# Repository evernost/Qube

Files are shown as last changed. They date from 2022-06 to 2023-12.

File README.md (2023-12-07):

# Qube
LED Rubik's Cube.



Parts list
-
| Part | Ref | Order code |
|---|---|---|
| µC | STM32G431KB  | Farnell: 3132405 |
| LED driver  | PCA9955B | Farnell: 2759859 |
| 3.3V LDO | LD1117S33CTR | Farnell: 1467779 |
| Push button | KSG222GLFS | Farnell: 2845714 |

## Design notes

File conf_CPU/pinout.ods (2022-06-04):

pin | designation | function (CPU) | function (PCB) | match?
1 | PE2 | SAI1_MCLK_A | AUDIO_I2S_MCLK
2 | PE3 | SAI1_SD_B | AUDIO_I2S_SD_ADC
3 | PE4 | SAI1_FS_A | AUDIO_I2S_LRCLK_DAC
4 | PE5 | SAI1_SCK_A | AUDIO_I2S_BCLK_DAC
5 | PE6 | SPI4_MOSI | SPI MOSI LEDs
6 | VBAT |  | VDD
7 | PC13 | not used | x
8 | PC14 | not used | x
9 | PC15 | not used | x
10 | PF0 | output | debug LED 0
11 | PF1 | output | debug LED 1
12 | PF2 | not used | x
13 | PF3 | not used | x
14 | PF4 | not used | x
15 | PF5 | not used | x
16 | VSS |  | GND
17 | VDD |  | VDD
18 | PF6 | not used | x
19 | PF7 | not used | x
20 | PF8 | SAI1_SCK_B | AUDIO_I2S_BCLK_ADC
21 | PF9 | SAI1_FS_B | AUDIO_I2S_LRCLK_ADC
22 | PF10 | display_en | display EN
23 | PH0 | osc_in | osc
24 | PH1 | osc_out | osc
25 | NRST
26 | PC0 | display_R5 | R5
27 | PC1 | SAI1_SD_A | AUDIO_I2S_SD_DAC
28 | PC2 | ADC3_INP0 | analog in 1
29 | PC3 | ADC3_INP1 | analog in 2
30 | VDD |  | VDD
31 | VSSA |  | GND
32 | VREF+
33 | VDDA |  | VDD
34 | PA0 | UART4_TX | UART vers PC
35 | PA1 | UART4_RX | UART depuis PC
36 | PA2 | output | buzzer
37 | PA3 | display_B5 | B5
38 | VSS |  | GND
39 | VDD |  | VDD
40 | PA4 | display_VSYNC | VSYNC
41 | PA5 | display_R4 | R4
42 | PA6 | display_G2 | G2
43 | PA7 | SPI1_MOSI | SPI audio MOSI
44 | PC4 | input | pb array
45 | PC5 | not used
46 | PB0 | display_R3 | R3
47 | PB1 | display_R6 | R6
48 | PB2 | QSPI_CLK | QSPI_CLK
49 | PF11 | not used | x
50 | PF12 | not used | x
51 | VSS |  | GND
52 | VDD |  | VDD
53 | PF13 | not used | x
54 | PF14 | not used | x
55 | PF15 | not used | x
56 | PG0 | output | TP debug
57 | PG1 | not used | x
58 | PE7 | QSPI_DATA_0 | QSPI0
59 | PE8 | QSPI_DATA_1 | QSPI1
60 | PE9 | QSPI_DATA_2 | QSPI2
61 | VSS |  | GND
62 | VDD |  | VDD
63 | PE10 | QSPI_DATA_3 | QSPI3
64 | PE11 | display_G3 | G3
65 | PE12 | SPI4_CLK | SPI CLK LEDs
66 | PE13 | output | SPI upd LEDs
67 | PE14 | display_CLK | pixel CLK
68 | PE15 | display_R7 | R7
69 | PB10 | display_G4 | G4
70 | PB11 | display_G5 | G5
71 | VCAP
72 | VDD |  | VDD
73 | PB12 | UART5_RX | MIDI in
74 | PB13 | UART5_TX | MIDI out
75 | PB14 | UART4_RTS | UART PC RTS
76 | PB15 | UART4_CTS | UART PC CTS
77 | PD8 | not used | x
78 | PD9 | not used | x
79 | PD10 | display_B3 | B3
80 | PD11 | output | MUX SEL A
81 | PD12 | output | MUX SEL B
82 | PD13 | output | MUX SEL C
83 | VSS |  | GND
84 | VDD |  | VDD
85 | PD14 | not used | x
86 | PD15 | not used | x
87 | PG2 | not used | x
88 | PG3 | not used | x
89 | PG4 | not used | x
90 | PG5 | not used | x
91 | PG6 | not used | x
92 | PG7 | not used | x
93 | PG8 | display_G7 | G7
94 | VSS |  | GND
95 | VDD
96 | PC6 | display_HSYNC | HSYNC
97 | PC7 | display_G6 | G6
98 | PC8 | not used | x
99 | PC9 | display_B2 | B2
100 | PA8 | not used | x
101 | PA9 | not used | x
102 | PA10 | display_B4 | B4
103 | PA11 | USB_OTG_N | USB N
104 | PA12 | USB_OTG_P | USB P
105 | PA13 | JTAG_TMS | JTAG TMS
106 | VCAP
107 | VSS |  | GND
108 | VDD |  | VDD
109 | PA14 | JTAG_TCK | JTAG TCK
110 | PA15 | JTAG_TDI | JTAG TDI
111 | PC10 | display_R2 | B4
112 | PC11 | QSPI_CSN | QSPI CSN
113 | PC12 | not used | x
114 | PD0 | not used | x
115 | PD1 | not used | x
116 | PD2 | not used | x
117 | PD3 | not used | x
118 | PD4 | not used | x
119 | PD5 | not used | x
120 | VSS |  | GND
121 | VDD |  | VDD
122 | PD6 | not used | x
123 | PD7 | output | DAC reset
124 | PG9 | SPI1_MISO | SPI audio MISO
125 | PG10 | SPI1_CSN | SPI audio MS
126 | PG11 | SPI1_CLK | SPI audio CLK
127 | PG12 | not used | x
128 | PG13 | not used | x
129 | PG14 | not used | x
130 | VSS |  | GND
131 | VDD |  | VDD
132 | PG15 | not used | x
133 | PB3 | JTAG_TDO | JTAG TDO
134 | PB4 | JTAG_TRST | JTAG TRST
135 | PB5 | not used | x
136 | PB6 | not used | x
137 | PB7 | not used | x
138 | BOOT0
139 | PB8 | display_B6 | B6
140 | PB9 | display_B7 | B7
141 | PE0 | not used | x
142 | PE1 | not used | x
143 | PDR_ON
144 | VDD |  | VDD

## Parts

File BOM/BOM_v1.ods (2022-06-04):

Catégorie | Description | Fabricant | Référence fabricant | Référence fournisseur | Fournisseur | Prix unitaire | Quantité | Commentaire
Actifs | 16 channels LED driver | NXP | PCA9955B | 2759859 | Farnell | 1,75 | 14
 | STM32 | ST | STM32G431KB | 3132405 | Farnell | 4,75 | 7
 | Régulateur 3.3V | ST | LD1117S33CTR | 1467779 | Farnell | 0,334 | 7
 | Bouton poussoir | C&K | KSG222GLFS | 2845714 | Farnell | 0,343 | 25

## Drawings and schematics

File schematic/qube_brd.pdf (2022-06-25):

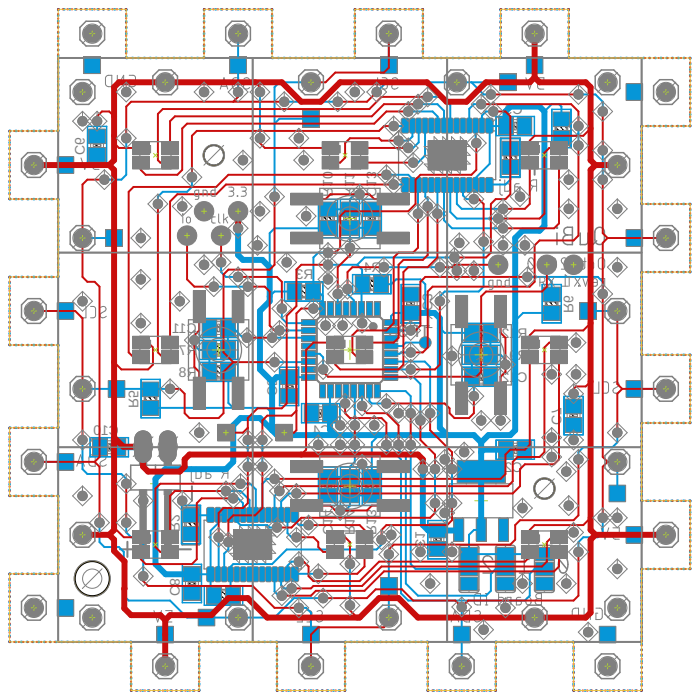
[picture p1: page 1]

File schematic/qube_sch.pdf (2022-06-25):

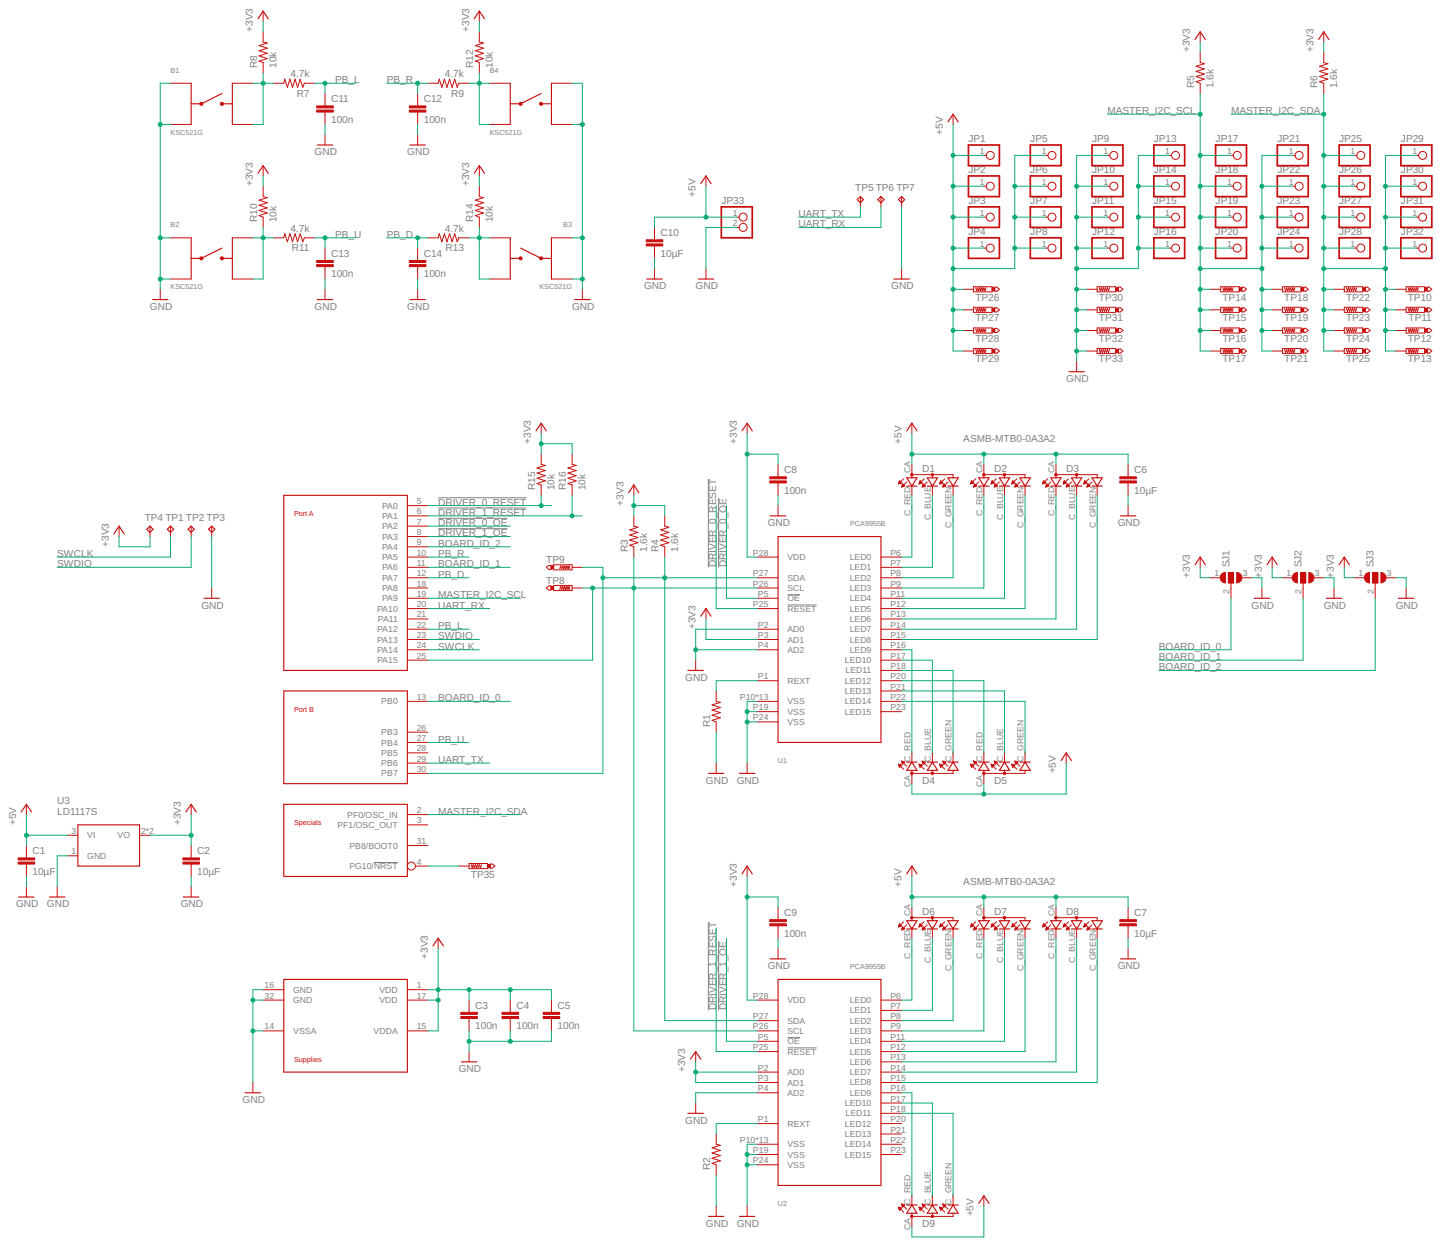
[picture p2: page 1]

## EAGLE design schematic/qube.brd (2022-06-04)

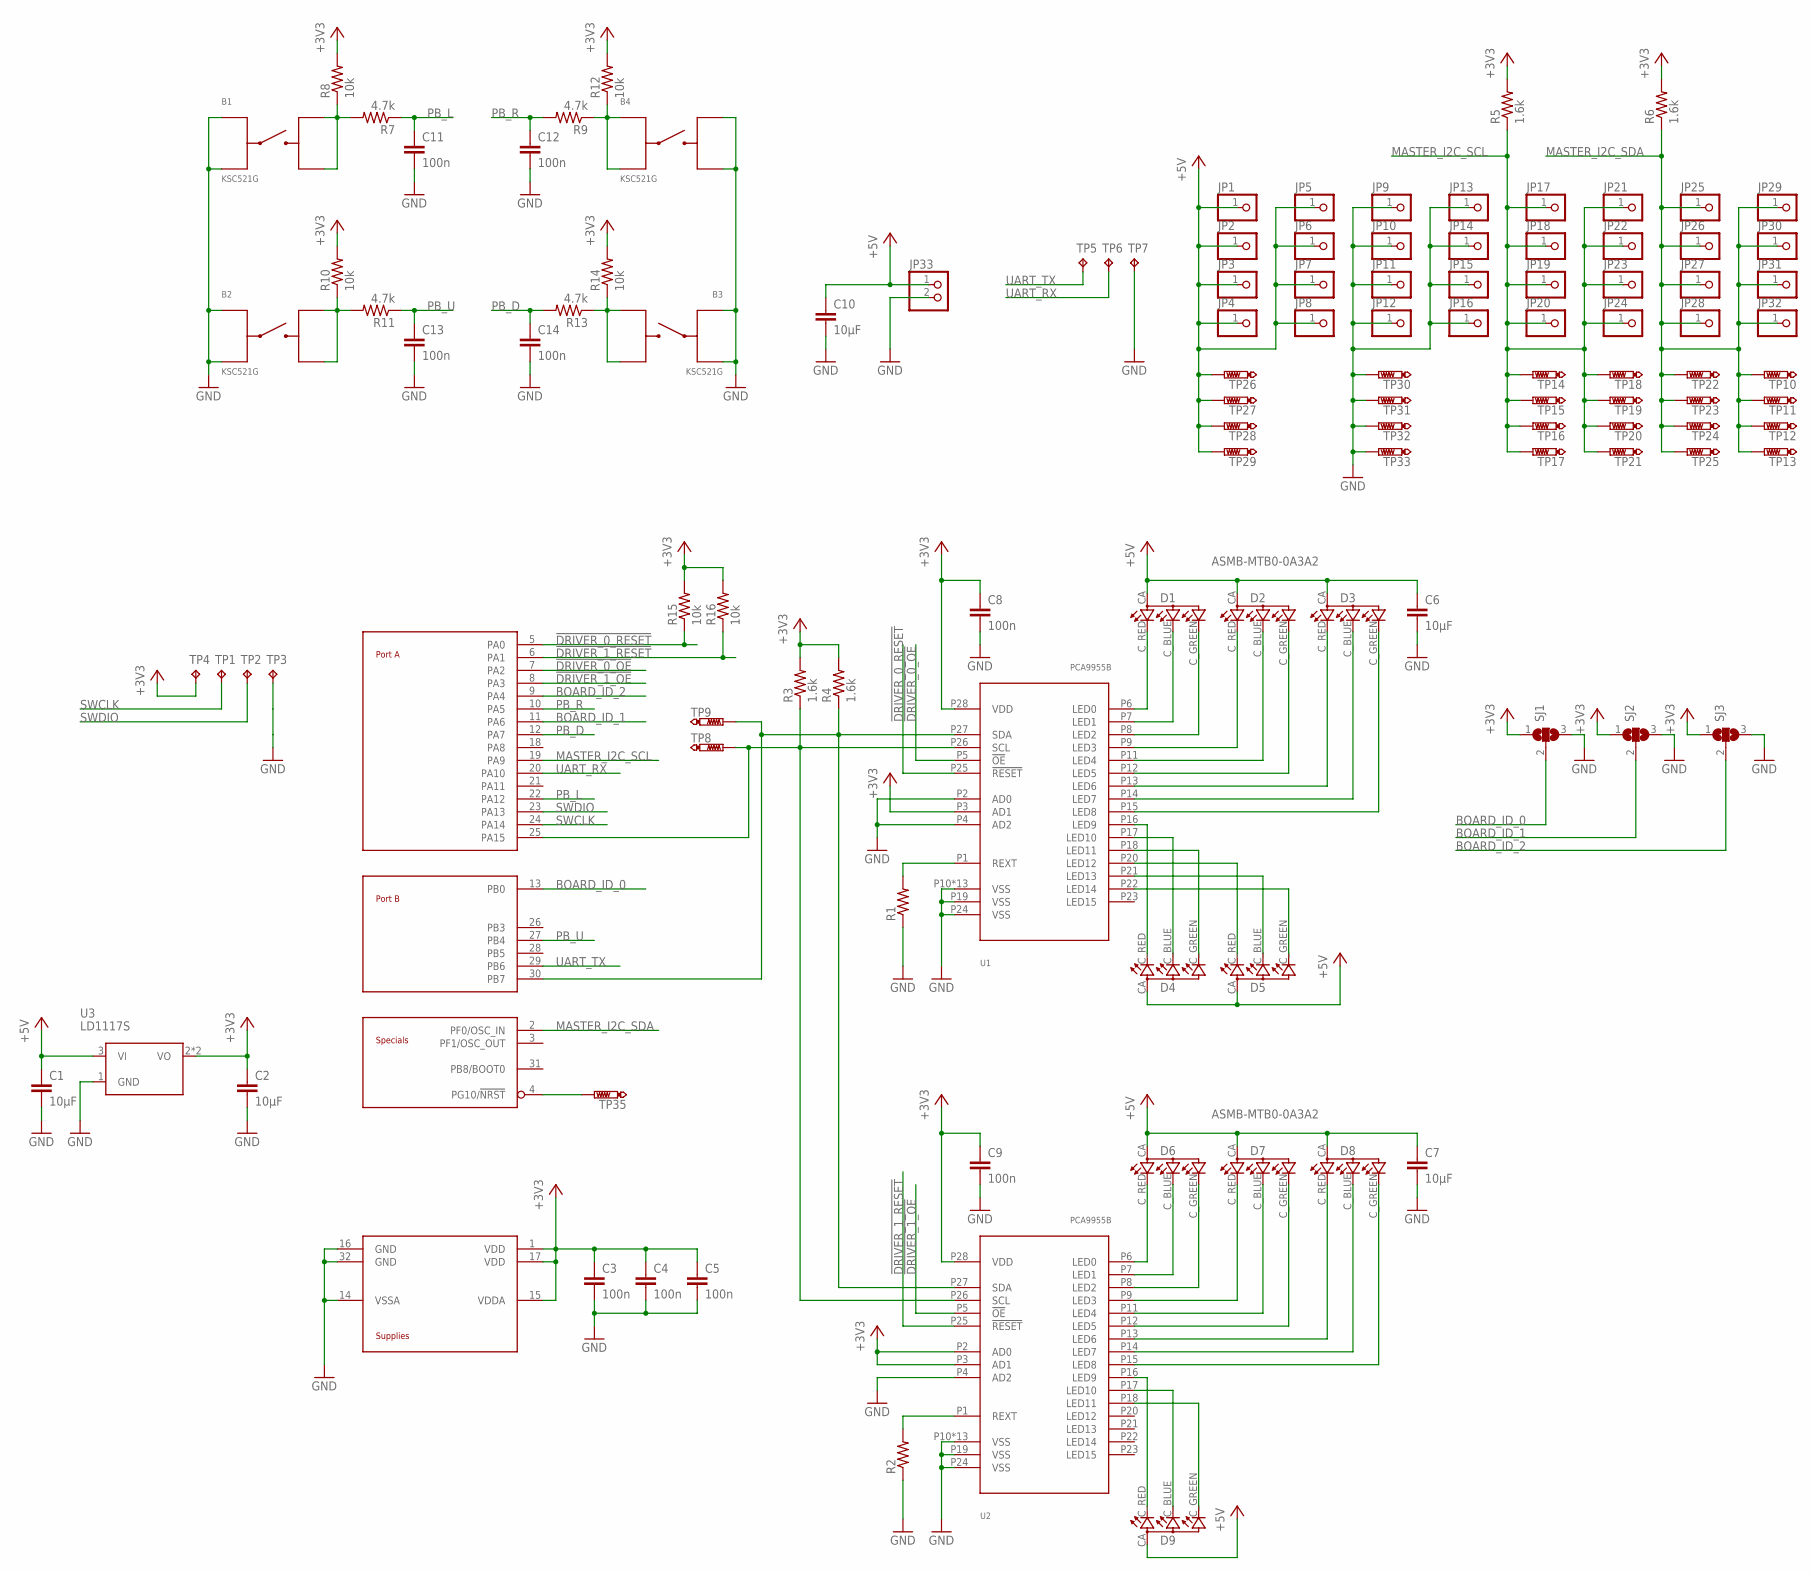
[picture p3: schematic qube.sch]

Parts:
B1, B2, B3, B4: KSC521G
C1, C2, C6, C7, C10: 10µF; C0805
C3, C4, C5, C8, C9, C11, C12, C13, C14: 100n; C0805
D1, D2, D3, D4, D5, D6, D7, D8, D9: ASMB-MTB0-0A3A2; PLCC-4
JP1, JP2, JP3, JP4, JP5, JP6, JP7, JP8, JP9, JP10, JP11, JP12, JP13, JP14, JP15, JP16, JP17, JP18, JP19, JP20, JP21, JP22, JP23, JP24, JP25, JP26, JP27, JP28, JP29, JP30, JP31, JP32: PINHD-1X1; 1X01
JP33: PINHD-1X2/90; 1X02/90
R1, R2: R-US_R0805; R0805
R3, R4, R5, R6: 1.6k; R0805
R7, R9, R11, R13: 4.7k; R0805
R8, R10, R12, R14, R15, R16: 10k; R0805
SJ1, SJ2, SJ3: SJ2W; SJ_2
TP1, TP2, TP3, TP4, TP5, TP6, TP7: TPTP18R; TP18R
TP8, TP9, TP10, TP11, TP12, TP13, TP14, TP15, TP16, TP17, TP18, TP19, TP20, TP21, TP22, TP23, TP24, TP25, TP26, TP27, TP28, TP29, TP30, TP31, TP32, TP33: PTR1TP15SQ; TP15SQ
TP35: PTR1TP10R; TP10R
U1, U2: PCA9955B; HTSSOP28
U3: LD1117S; SOT223
U$1: STM32G431KB; LQFP32

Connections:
!DRIVER_0_OE: U1.P5 (!OE), U$1.7 (PA2)
!DRIVER_0_RESET: R15.1, U1.P25 (!RESET), U$1.5 (PA0)
!DRIVER_1_OE: U2.P5 (!OE), U$1.8 (PA3)
!DRIVER_1_RESET: R16.1, U2.P25 (!RESET), U$1.6 (PA1)
+3V3: C2.1, C3.1, C4.1, C5.1, C8.1, C9.1, R3.2, R4.2, R5.2, R6.2, R8.2, R10.2, R12.2, R14.2, R15.2, R16.2, SJ1.1, SJ2.1, SJ3.1, TP4.TP, U1.P3 (AD1), U1.P28 (VDD), U2.P2 (AD0), U2.P3 (AD1), U2.P28 (VDD), U3.2 (VO), U3.4 (VO), U$1.1 (VDD), U$1.15 (VDDA), U$1.17 (VDD)
+5V: C1.1, C6.1, C7.1, C10.1, D1.CA (A2), D2.CA (A2), D3.CA (A2), D4.CA (A2), D5.CA (A2), D6.CA (A2), D7.CA (A2), D8.CA (A2), D9.CA (A2), JP1.1, JP2.1, JP3.1, JP4.1, JP5.1, JP6.1, JP7.1, JP8.1, JP33.1, TP26.TP, TP27.TP, TP28.TP, TP29.TP, U3.3 (VI)
BOARD_ID_0: SJ1.2, U$1.13 (PB0)
BOARD_ID_1: SJ2.2, U$1.11 (PA6)
BOARD_ID_2: SJ3.2, U$1.9 (PA4)
GND: B1.3, B1.4, B2.3, B2.4, B3.3, B3.4, B4.1, B4.2, C1.2, C2.2, C3.2, C4.2, C5.2, C6.2, C7.2, C8.2, C9.2, C10.2, C11.2, C12.2, C13.2, C14.2, JP9.1, JP10.1, JP11.1, JP12.1, JP13.1, JP14.1, JP15.1, JP16.1, JP33.2, R1.1, R2.1, SJ1.3, SJ2.3, SJ3.3, TP3.TP, TP7.TP, TP30.TP, TP31.TP, TP32.TP, TP33.TP, U1.P2 (AD0), U1.P4 (AD2), U1.P10 (VSS), U1.P19 (VSS), U1.P24 (VSS), U1.PWR_PAD1 (VSS), U1.PWR_PAD2 (VSS), U1.PWR_PAD3 (VSS), U1.PWR_PAD4 (VSS), U1.PWR_PAD5 (VSS), U1.PWR_PAD6 (VSS), U1.PWR_PAD7 (VSS), U1.PWR_PAD8 (VSS), U1.PWR_PAD9 (VSS), U1.PWR_PAD10 (VSS), U1.PWR_PAD11 (VSS), U1.PWR_PAD12 (VSS), U2.P4 (AD2), U2.P10 (VSS), U2.P19 (VSS), U2.P24 (VSS), U2.PWR_PAD1 (VSS), U2.PWR_PAD2 (VSS), U2.PWR_PAD3 (VSS), U2.PWR_PAD4 (VSS), U2.PWR_PAD5 (VSS), U2.PWR_PAD6 (VSS), U2.PWR_PAD7 (VSS), U2.PWR_PAD8 (VSS), U2.PWR_PAD9 (VSS), U2.PWR_PAD10 (VSS), U2.PWR_PAD11 (VSS), U2.PWR_PAD12 (VSS), U3.1 (GND), U$1.14 (VSSA), U$1.16 (GND), U$1.32 (GND)
MASTER_I2C_SCL: JP17.1, JP18.1, JP19.1, JP20.1, JP21.1, JP22.1, JP23.1, JP24.1, R5.1, TP14.TP, TP15.TP, TP16.TP, TP17.TP, TP18.TP, TP19.TP, TP20.TP, TP21.TP, U$1.19 (PA9)
MASTER_I2C_SDA: JP25.1, JP26.1, JP27.1, JP28.1, JP29.1, JP30.1, JP31.1, JP32.1, R6.1, TP10.TP, TP11.TP, TP12.TP, TP13.TP, TP22.TP, TP23.TP, TP24.TP, TP25.TP, U$1.2 (PF0/OSC_IN)
unnamed: R1.2, U1.P1 (REXT)
unnamed: R2.2, U2.P1 (REXT)
unnamed: D1.C_RED (CRED), U1.P6 (LED0)
unnamed: D1.C_BLUE (CBLUE), U1.P7 (LED1)
unnamed: D1.C_GREEN (CGREEN), U1.P8 (LED2)
unnamed: D2.C_RED (CRED), U1.P9 (LED3)
unnamed: D2.C_BLUE (CBLUE), U1.P11 (LED4)
unnamed: D2.C_GREEN (CGREEN), U1.P12 (LED5)
unnamed: D3.C_RED (CRED), U1.P13 (LED6)
unnamed: D3.C_BLUE (CBLUE), U1.P14 (LED7)
unnamed: D3.C_GREEN (CGREEN), U1.P15 (LED8)
unnamed: D4.C_RED (CRED), U1.P16 (LED9)
unnamed: D4.C_BLUE (CBLUE), U1.P17 (LED10)
unnamed: D4.C_GREEN (CGREEN), U1.P18 (LED11)
unnamed: D5.C_RED (CRED), U1.P20 (LED12)
unnamed: D5.C_BLUE (CBLUE), U1.P21 (LED13)
unnamed: D5.C_GREEN (CGREEN), U1.P22 (LED14)
unnamed: D6.C_RED (CRED), U2.P6 (LED0)
unnamed: D6.C_BLUE (CBLUE), U2.P7 (LED1)
unnamed: D6.C_GREEN (CGREEN), U2.P8 (LED2)
unnamed: D7.C_RED (CRED), U2.P9 (LED3)
unnamed: D7.C_BLUE (CBLUE), U2.P11 (LED4)
unnamed: D7.C_GREEN (CGREEN), U2.P12 (LED5)
unnamed: D8.C_RED (CRED), U2.P13 (LED6)
unnamed: D8.C_BLUE (CBLUE), U2.P14 (LED7)
unnamed: D8.C_GREEN (CGREEN), U2.P15 (LED8)
unnamed: D9.C_RED (CRED), U2.P16 (LED9)
unnamed: D9.C_BLUE (CBLUE), U2.P17 (LED10)
unnamed: D9.C_GREEN (CGREEN), U2.P18 (LED11)
unnamed: R3.1, TP8.TP, U1.P26 (SCL), U2.P26 (SCL), U$1.25 (PA15)
unnamed: R4.1, TP9.TP, U1.P27 (SDA), U2.P27 (SDA), U$1.30 (PB7)
unnamed: B1.1, B1.2, R7.2, R8.1
unnamed: B3.1, B3.2, R13.1, R14.1
unnamed: B4.3, B4.4, R9.1, R12.1
unnamed: TP35.TP, U$1.4 (PG10/!NRST)
unnamed: B2.1, B2.2, R10.1, R11.2
PB_D: C14.1, R13.2, U$1.12 (PA7)
PB_L: C11.1, R7.1, U$1.22 (PA12)
PB_R: C12.1, R9.2, U$1.10 (PA5)
PB_U: C13.1, R11.1, U$1.27 (PB4)
SWCLK: TP1.TP, U$1.24 (PA14)
SWDIO: TP2.TP, U$1.23 (PA13)
UART_RX: TP6.TP, U$1.20 (PA10)
UART_TX: TP5.TP, U$1.29 (PB6)

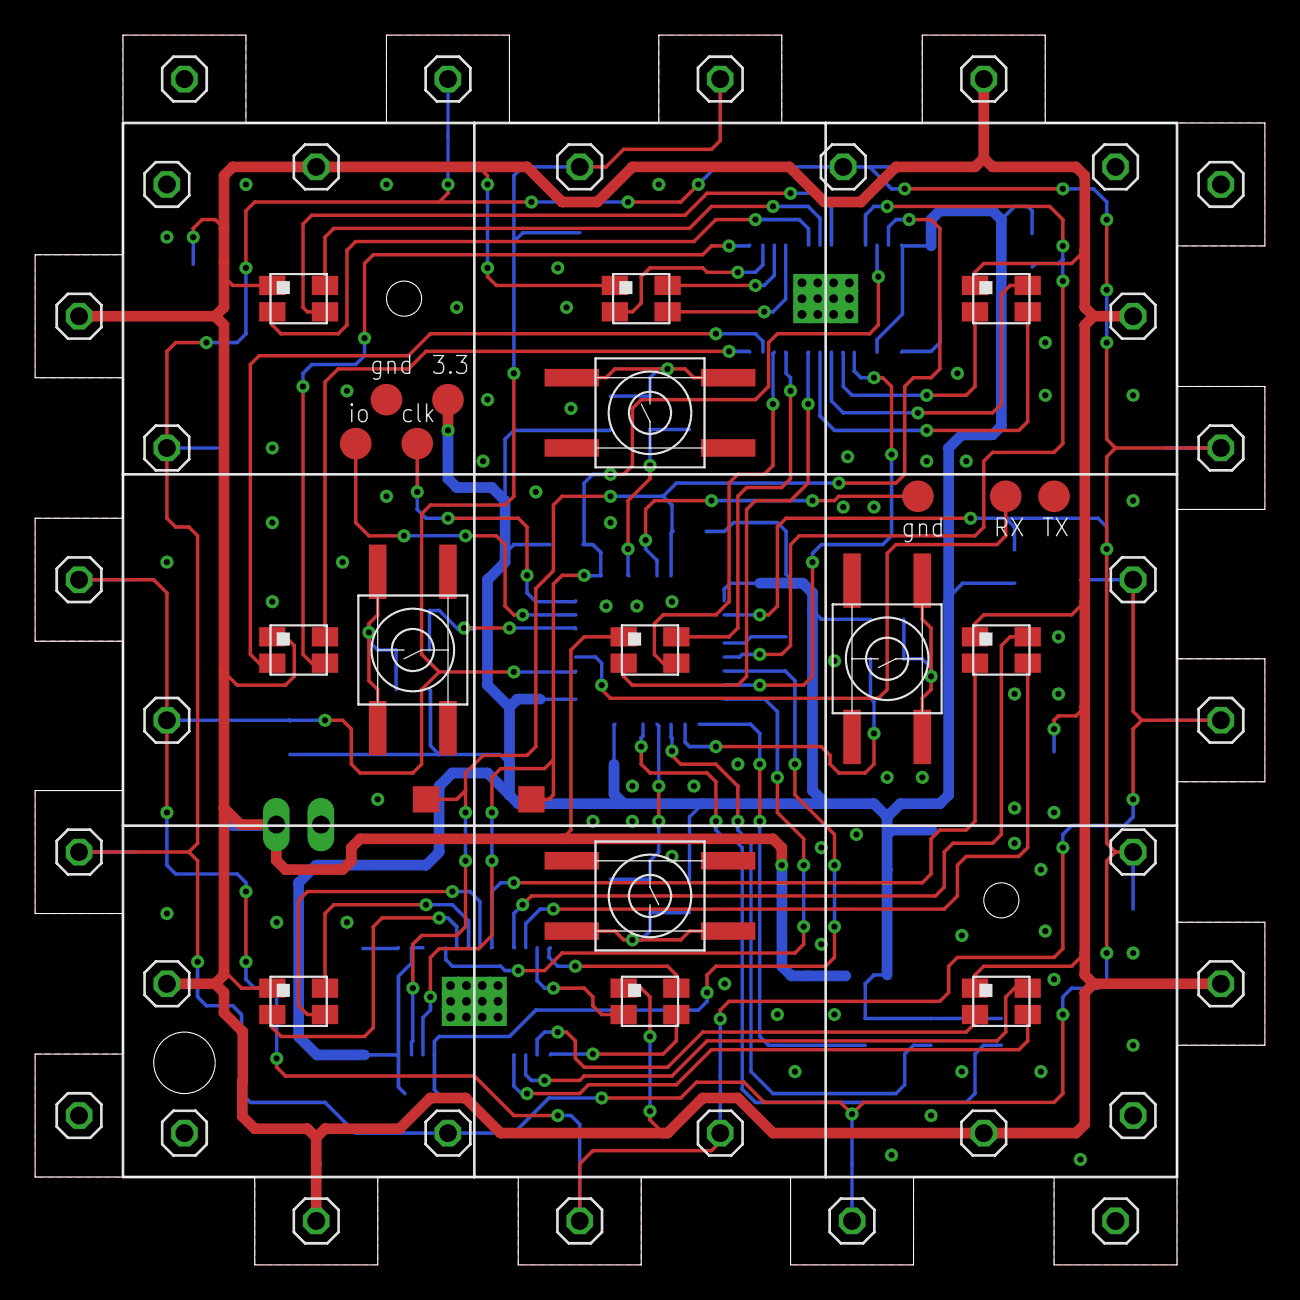
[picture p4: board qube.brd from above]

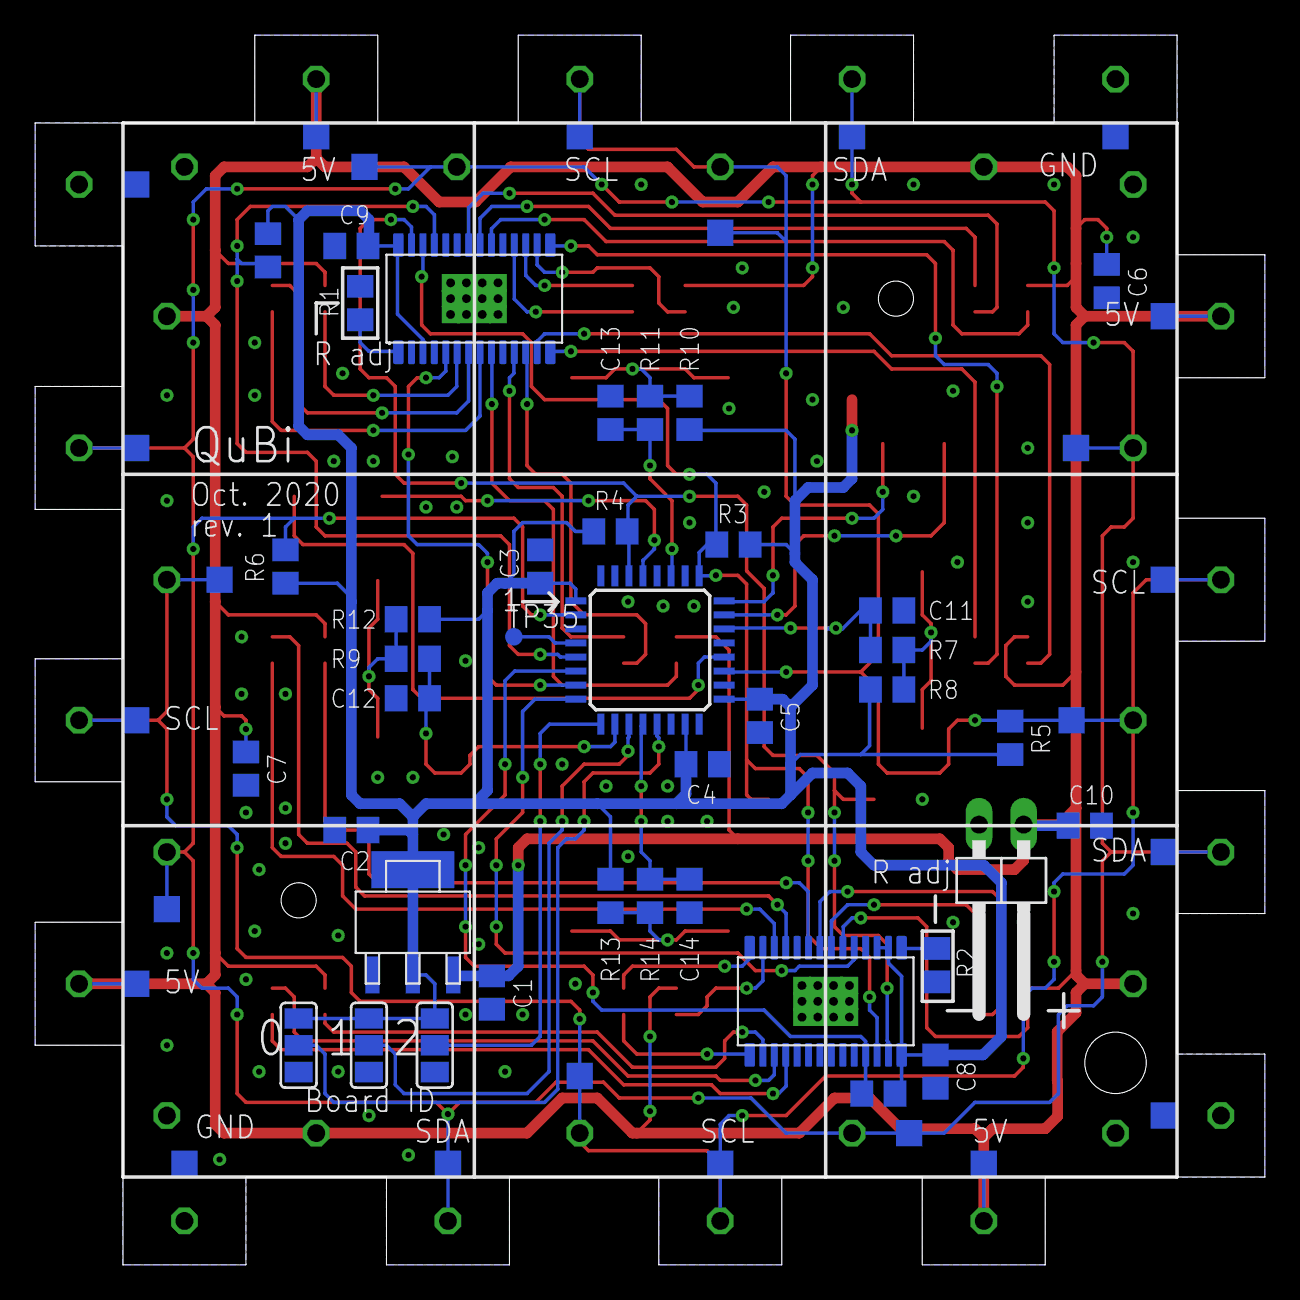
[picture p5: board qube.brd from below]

Board: 2 copper layers, 70.0 x 70.0 mm, 117 parts (63 on the bottom side), 56 nets.

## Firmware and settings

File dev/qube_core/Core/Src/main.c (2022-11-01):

// ============================================================================
// Module name    : main 
// File name      : main.c
// Purpose        : Qube entry point
// Author         : Quentin Biache
// Creation date  : June 4th, 2022
// ============================================================================

// ============================================================================
// Description
// ============================================================================
// Qube application entry point.

// ============================================================================
// Includes
// ============================================================================
#include "main.h"
#include "cpu.h"
#include "led.h"
#include "push_button.h"
#include "cube.h"

// Private variables ----------------------------------------------------------

// Private function prototypes ------------------------------------------------


// ============================================================================
// Main code
// ============================================================================
int main(void)
{

  // Array of RGB 6 faces x 9 LEDs representing the cube
  rgbLedType cube[6][9];
  
  uint8_t pb[6] = {0};
  uint8_t state = 0;


  // -----------------
  // MCU configuration
  // -----------------
  cpuInit();

  // Read the board ID
  uint8_t boardID = getBoardID();

  // Initialise the LED driver
  HAL_Delay(1);
  ledInitDriver();
  
  // Init the colors of each face
  paintFace(cube[CUBE_FACE_F], ORANGE_LED);
  paintFace(cube[CUBE_FACE_B], RED_LED);
  paintFace(cube[CUBE_FACE_L], BLUE_LED);
  paintFace(cube[CUBE_FACE_R], GREEN_LED);
  paintFace(cube[CUBE_FACE_U], PINK_LED);
  paintFace(cube[CUBE_FACE_D], YELLOW_LED);
  
  // Commit the changes to the LEDs
  ledUpdateFace(cube, CUBE_FACE_F);

  // --------------------------------------------------------------------------
  // Main loop
  // --------------------------------------------------------------------------
  
  // Use this to tune colors
  // cube[CUBE_FACE_F][F_UL] = LED_RED;
  // cube[CUBE_FACE_F][F_ML] = LED_GREEN;
  // cube[CUBE_FACE_F][F_DL] = LED_BLUE;
  // cube[CUBE_FACE_F][F_UM] = LED_YELLOW;
  // cube[CUBE_FACE_F][F_MM] = LED_ORANGE;
  // cube[CUBE_FACE_F][F_DM] = LED_VIOLET;
  // cube[CUBE_FACE_F][F_UR] = LED_WHITE;
  // cube[CUBE_FACE_F][F_MR] = LED_PINK;
  // cube[CUBE_FACE_F][F_DR] = LED_RED;
  // ledUpdateFace(cube, CUBE_FACE_F);

  while (1)
  {

    if (timer2_expired)
    {
      timer2_expired = 0;

      if (state == 0)
      {
        move(cube, CUBE_FACE_D, ROTATE_90);
        ledUpdateFace(cube, CUBE_FACE_F);
        state = 1;
      }
      else if (state == 1)
      {
        move(cube, CUBE_FACE_R, ROTATE_90);
        ledUpdateFace(cube, CUBE_FACE_F);
        state = 2;
      }
      else if (state == 2)
      {
        move(cube, CUBE_FACE_U, ROTATE_90);      
        ledUpdateFace(cube, CUBE_FACE_F);
        state = 3;
      }
      else if (state == 3)
      {
        move(cube, CUBE_FACE_L, ROTATE_90);
        ledUpdateFace(cube, CUBE_FACE_F);
        state = 4;
      }
      else
      {
        move(cube, CUBE_FACE_F, ROTATE_90);
        ledUpdateFace(cube, CUBE_FACE_F);
        state = 0;
      }

      // Probe the push button arrays (one hot coding)
      pb[CUBE_FACE_F] = 0U;
      pb[CUBE_FACE_F] |= (HAL_GPIO_ReadPin(PB_left_GPIO_Port, PB_left_Pin)    == 0 ? PB_L_MASK : 0x00);
      pb[CUBE_FACE_F] |= (HAL_GPIO_ReadPin(PB_right_GPIO_Port, PB_right_Pin)  == 0 ? PB_R_MASK : 0x00);
      pb[CUBE_FACE_F] |= (HAL_GPIO_ReadPin(PB_up_GPIO_Port, PB_up_Pin)        == 0 ? PB_U_MASK : 0x00);
      pb[CUBE_FACE_F] |= (HAL_GPIO_ReadPin(PB_down_GPIO_Port, PB_down_Pin)    == 0 ? PB_D_MASK : 0x00);

      // Request push button status on the other boards
      //PB_array[FACE_B] = getPushButtons(); 
      //PB_array[FACE_L] = getPushButtons();
      //PB_array[FACE_R] = getPushButtons();
      //PB_array[FACE_U] = getPushButtons();
      //PB_array[FACE_D] = getPushButtons();
    }
  }


  return 0;
}

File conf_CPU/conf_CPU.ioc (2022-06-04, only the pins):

Mcu.UserName=STM32G431KBTx
PA0.GPIO_Label=DRIVER_0_RESET
PA0.Signal=GPIO_Output
PA1.GPIO_Label=DRIVER_1_RESET
PA1.Signal=GPIO_Output
PA10.Signal=USART1_RX
PA12.GPIO_Label=PB_left
PA12.Signal=GPIO_Input
PA13.Signal=SYS_JTMS-SWDIO
PA14.Signal=SYS_JTCK-SWCLK
PA15.GPIO_Label=I2C1_LED_DRV_SCL
PA15.Signal=I2C1_SCL
PA2.GPIO_Label=DRIVER_0_OE
PA2.Signal=GPIO_Output
PA3.GPIO_Label=DRIVER_1_OE
PA3.Signal=GPIO_Output
PA4.GPIO_Label=BOARD_ID_0
PA4.Signal=GPIO_Input
PA5.GPIO_Label=PB_right
PA5.Signal=GPIO_Input
PA6.GPIO_Label=BOARD_ID_1
PA6.Signal=GPIO_Input
PA7.GPIO_Label=PB_down
PA7.Signal=GPIO_Input
PA9.GPIO_Label=I2C2_COMM_SCL
PA9.Signal=I2C2_SCL
PB0.GPIO_Label=BOARD_ID_2
PB0.Signal=GPIO_Input
PB4.GPIO_Label=PB_up
PB4.Signal=GPIO_Input
PB6.Signal=USART1_TX
PB7.GPIO_Label=I2C1_LED_DRV_SDA
PB7.Signal=I2C1_SDA
PB8-BOOT0.Signal=GPIO_Output
PF0-OSC_IN.GPIO_Label=I2C2_COMM_SDA
PF0-OSC_IN.Signal=I2C2_SDA

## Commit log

2022-06-04 First upload of the current progress state.
    [BOM_v1.ods, PCA9955B_footprint.ods, mating.ods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]
2022-11-01 - Deleted unused "common.h" - Code rework and cleanup - Changed for more consistent variable names
    [cpu.h, cube.c, led.c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]
